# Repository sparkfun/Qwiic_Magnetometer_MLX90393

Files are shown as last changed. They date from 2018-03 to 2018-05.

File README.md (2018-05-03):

SparkFun Qwiic Magnetometer MLX90393
========================================

Qwiic Magnetometer

[*SparkFun Qwiic Magnetometer MLX90393 (14571)*](https://www.sparkfun.com/products/14571)

The SparkFun MLX90393 Magnetometer Breakout is a triple-axis magnetic sensor board capable of sensing very small fields (like the Earth’s magnetic field), while still behaving as one would expect during saturation in larger fields (like a nearby magnet). The MLX90393 breakout can be used as a compass sensor but also works well as a non-contact controller, a flow meter with a magnetic impeller, or a linear actuator position sensor. To make it even easier to to get your readings, all communication is enacted exclusively via I2C, utilizing our handy Qwiic system. However, we still have broken out 0.1"-spaced pins in case you prefer to use a breadboard.

Repository Contents
-------------------

* **/Hardware** - Eagle design files (.brd, .sch)
* **/Production** - Production panel files (.brd)
* **/Software** - Example Code

Documentation
--------------
* **[Arduino Library](https://github.com/tedyapo/arduino-MLX90393)** - Arduino library MLX90393 magnetometer sensor.
* **[Hookup Guide](https://learn.sparkfun.com/tutorials/qwiic-magnetometer-mlx90393-hookup-guide)** - Basic hookup guide for the SparkFun Qwiic Magnetometer MLX90393.
* **[SparkFun Fritzing repo](https://github.com/sparkfun/Fritzing_Parts)** - Fritzing diagrams for SparkFun products. 

License Information
-------------------

This product is _**open source**_! 

Please review the LICENSE.md file for license information. 

If you have any questions or concerns on licensing, please contact techsupport@sparkfun.com.

Distributed as-is; no warranty is given.

- Your friends at SparkFun.

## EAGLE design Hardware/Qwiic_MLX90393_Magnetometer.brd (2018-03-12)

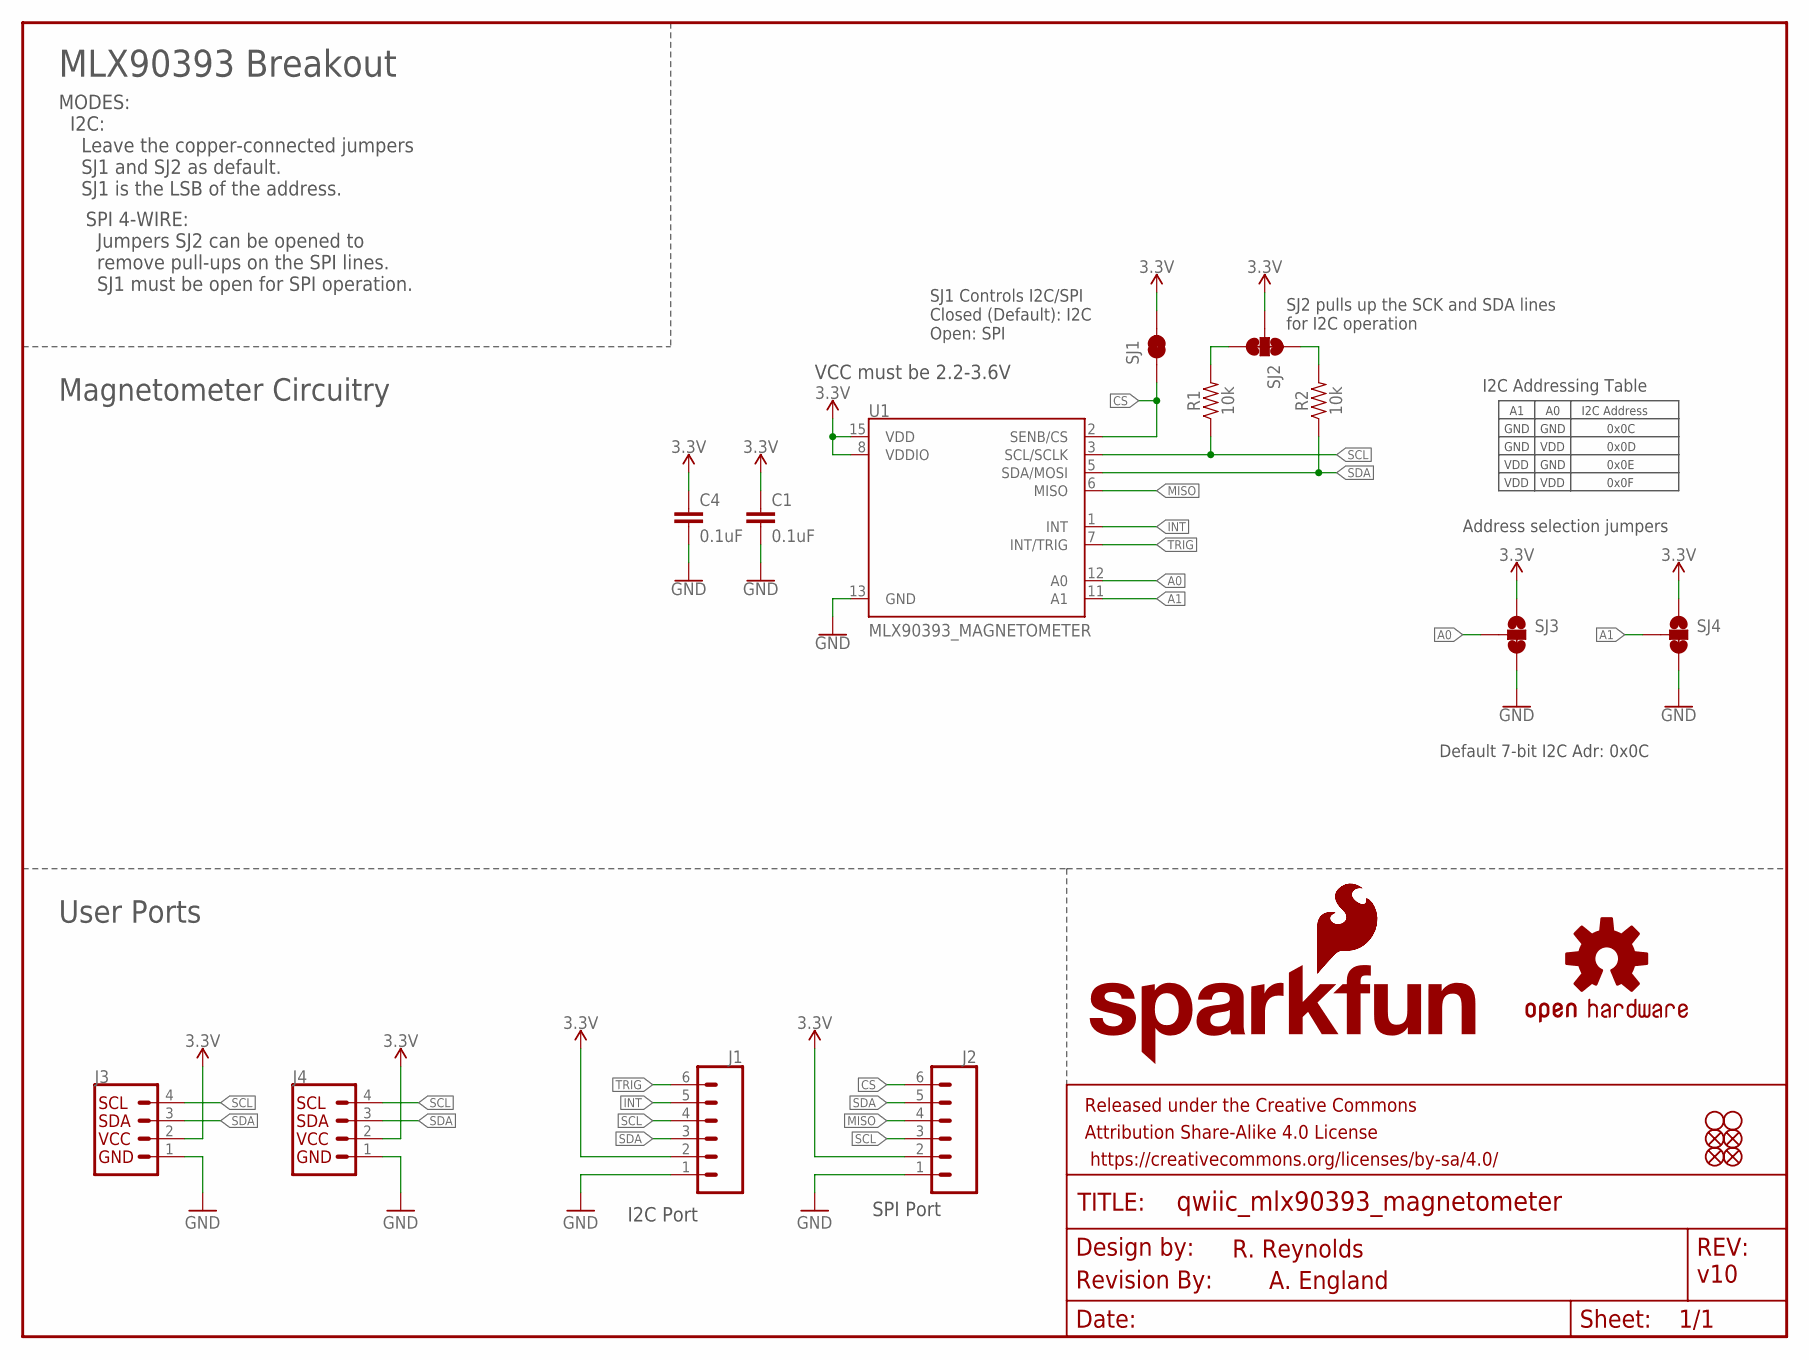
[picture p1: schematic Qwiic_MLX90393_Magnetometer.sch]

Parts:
C1, C4: 0.1uF; 0603
FD1, FD2, FD3, FD4: FIDUCIALUFIDUCIAL; FIDUCIAL-MICRO
FRAME2: FRAME-LETTER; CREATIVE_COMMONS
J1, J2: CONN_06NO_SILK_FEMALE_PTH; 1X06_NO_SILK
J3, J4: QWIIC_CONNECTORJS-1MM; 1X04_1MM_RA
JP3, JP4: STAND-OFF
LOGO1: SFE_LOGO_NAME_FLAME.1_INCH; SFE_LOGO_NAME_FLAME_.1
LOGO2: SFE_LOGO_FLAME.1_INCH; SFE_LOGO_FLAME_.1
LOGO3: REVISION
R1, R2: 10k; 0603
SJ1: JUMPER-SMT_2_NC_TRACE_SILK; SMT-JUMPER_2_NC_TRACE_SILK
SJ2: JUMPER-PAD-3-NC_BY_TRACE; PAD-JUMPER-3-3OF3_NC_BY_TRACE_YES_SILK_FULL_BOX
SJ3, SJ4: JUMPER-SMT_3_1-NC_TRACE_SILK; SMT-JUMPER_3_1-NC_TRACE_SILK
U1: MLX90393_MAGNETOMETER; QFN-16_WITH_AXIES
U$1: OSHW-LOGOS; OSHW-LOGO-S

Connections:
3.3V: C1.1, C4.1, J1.2, J2.2, J3.2, J4.2, SJ1.2, SJ2.2, SJ3.1, SJ4.1, U1.8 (VDDIO), U1.15 (VDD)
A0: SJ3.2, U1.12 (A0)
A1: SJ4.2, U1.11 (A1)
CS: J2.6, SJ1.1, U1.2 (SENB/CS)
GND: C1.2, C4.2, J1.1, J2.1, J3.1, J4.1, SJ3.3, SJ4.3, U1.13 (GND)
INT: J1.5, U1.1 (INT)
MISO: J2.4, U1.6 (MISO)
unnamed: R2.2, SJ2.1
unnamed: R1.2, SJ2.3
SCL: J1.4, J2.3, J3.4, J4.4, R1.1, U1.3 (SCL/SCLK)
SDA: J1.3, J2.5, J3.3, J4.3, R2.1, U1.5 (SDA/MOSI)
TRIG: J1.6, U1.7 (INT/TRIG)

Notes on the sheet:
Address selection jumpers
v10
R. Reynolds
MLX90393 Breakout
SJ2 pulls up the SCK and SDA lines for I2C operation
MODES: I2C: Leave the copper-connected jumpers SJ1 and SJ2 as default. SJ1 is the LSB of the address.
Magnetometer Circuitry
User Ports
VCC must be 2.2-3.6V
SJ1 Controls I2C/SPI Closed (Default): I2C Open: SPI
I2C Port
SPI Port
I2C Address
0x0C
0x0D
0x0E
0x0F
GND
VDD
SPI 4-WIRE: Jumpers SJ2 can be opened to remove pull-ups on the SPI lines. SJ1 must be open for SPI operation.
I2C Addressing Table
Default 7-bit I2C Adr: 0x0C
A. England

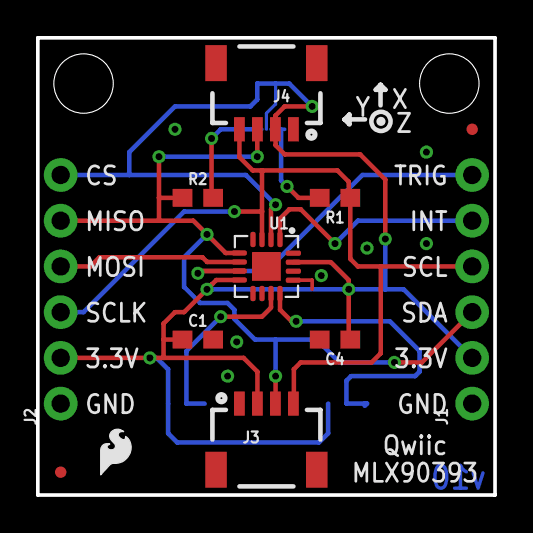
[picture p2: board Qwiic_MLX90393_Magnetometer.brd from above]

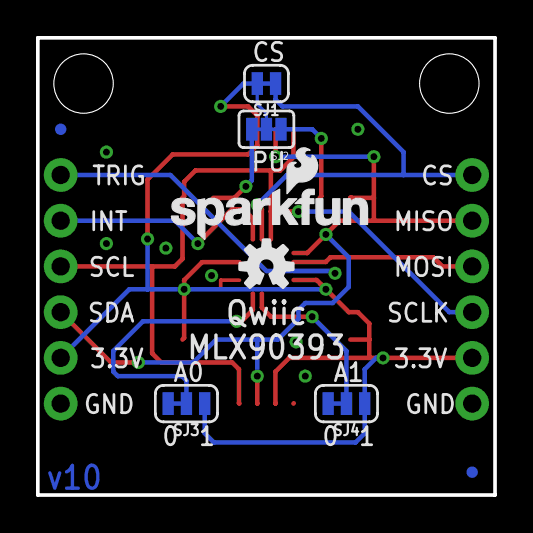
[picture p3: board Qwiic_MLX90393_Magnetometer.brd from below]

Board: 2 copper layers, 25.4 x 25.4 mm, 24 parts (8 on the bottom side), 12 nets.

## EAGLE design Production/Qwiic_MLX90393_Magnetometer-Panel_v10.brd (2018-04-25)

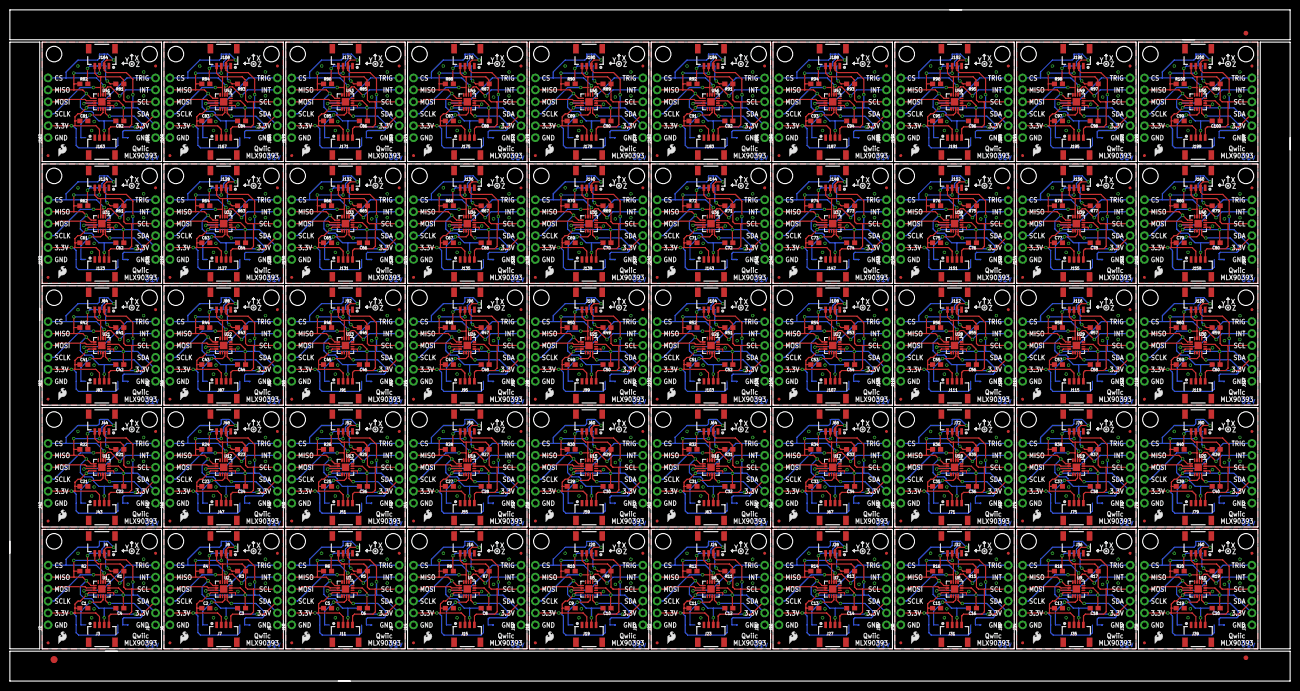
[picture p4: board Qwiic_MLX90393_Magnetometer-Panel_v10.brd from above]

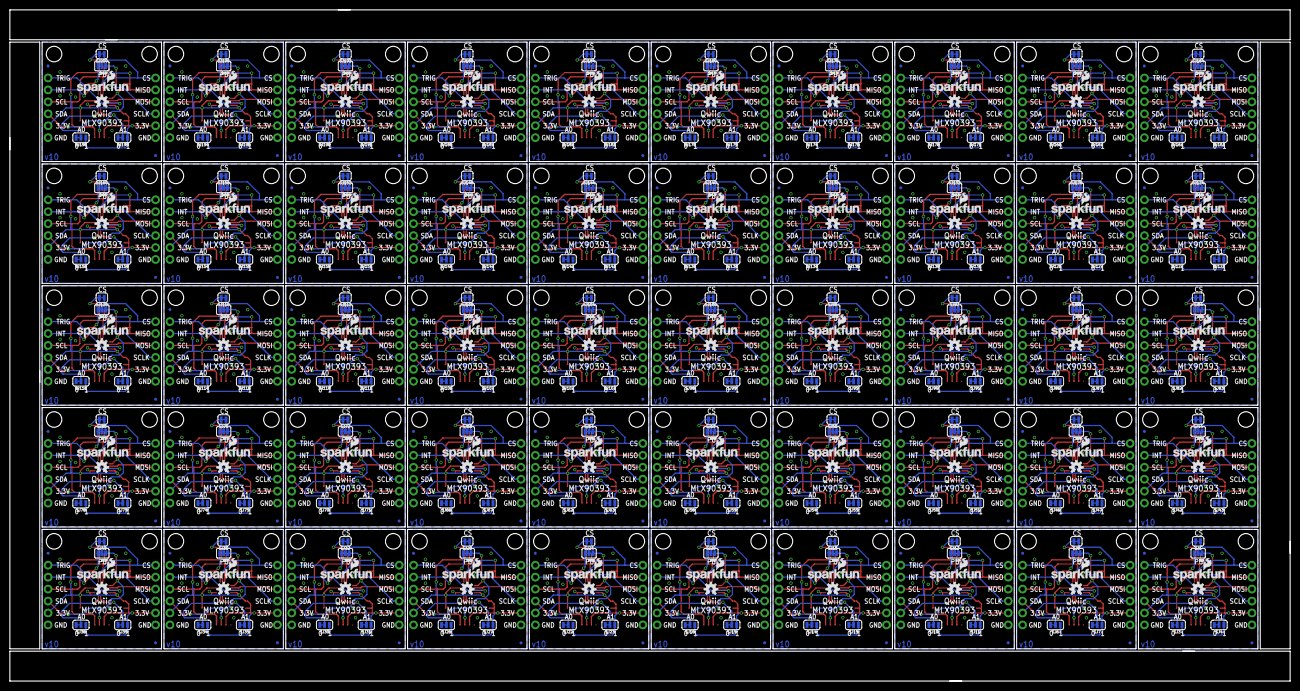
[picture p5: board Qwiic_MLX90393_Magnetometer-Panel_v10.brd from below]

Board: 2 copper layers, 272.3 x 142.7 mm, 1103 parts (400 on the bottom side), 600 nets.

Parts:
C1, C2, C3, C4, C5, C6, C7, C8, C9, C10, C11, C12, C13, C14, C15, C16, C17, C18, C19, C20, C21, C22, C23, C24, C25, C26, C27, C28, C29, C30, C31, C32, C33, C34, C35, C36, C37, C38, C39, C40, C41, C42, C43, C44, C45, C46, C47, C48, C49, C50, C51, C52, C53, C54, C55, C56, C57, C58, C59, C60, C61, C62, C63, C64, C65, C66, C67, C68, C69, C70, C71, C72, C73, C74, C75, C76, C77, C78, C79, C80, C81, C82, C83, C84, C85, C86, C87, C88, C89, C90, C91, C92, C93, C94, C95, C96, C97, C98, C99, C100: 0.1uF; 0603
E$1: FIDUCIAL-1.5X3
E$6, E$7: FIDUCIAL-1X2
FD1, FD2, FD3, FD4, FD5, FD6, FD7, FD8, FD9, FD10, FD11, FD12, FD13, FD14, FD15, FD16, FD17, FD18, FD19, FD20, FD21, FD22, FD23, FD24, FD25, FD26, FD27, FD28, FD29, FD30, FD31, FD32, FD33, FD34, FD35, FD36, FD37, FD38, FD39, FD40, FD41, FD42, FD43, FD44, FD45, FD46, FD47, FD48, FD49, FD50, FD51, FD52, FD53, FD54, FD55, FD56, FD57, FD58, FD59, FD60, FD61, FD62, FD63, FD64, FD65, FD66, FD67, FD68, FD69, FD70, FD71, FD72, FD73, FD74, FD75, FD76, FD77, FD78, FD79, FD80, FD81, FD82, FD83, FD84, FD85, FD86, FD87, FD88, FD89, FD90, FD91, FD92, FD93, FD94, FD95, FD96, FD97, FD98, FD99, FD100, FD101, FD102, FD103, FD104, FD105, FD106, FD107, FD108, FD109, FD110, FD111, FD112, FD113, FD114, FD115, FD116, FD117, FD118, FD119, FD120, FD121, FD122, FD123, FD124, FD125, FD126, FD127, FD128, FD129, FD130, FD131, FD132, FD133, FD134, FD135, FD136, FD137, FD138, FD139, FD140, FD141, FD142, FD143, FD144, FD145, FD146, FD147, FD148, FD149, FD150, FD151, FD152, FD153, FD154, FD155, FD156, FD157, FD158, FD159, FD160, FD161, FD162, FD163, FD164, FD165, FD166, FD167, FD168, FD169, FD170, FD171, FD172, FD173, FD174, FD175, FD176, FD177, FD178, FD179, FD180, FD181, FD182, FD183, FD184, FD185, FD186, FD187, FD188, FD189, FD190, FD191, FD192, FD193, FD194, FD195, FD196, FD197, FD198, FD199, FD200: FIDUCIALUFIDUCIAL; FIDUCIAL-MICRO
J1, J2, J5, J6, J9, J10, J13, J14, J17, J18, J21, J22, J25, J26, J29, J30, J33, J34, J37, J38, J41, J42, J45, J46, J49, J50, J53, J54, J57, J58, J61, J62, J65, J66, J69, J70, J73, J74, J77, J78, J81, J82, J85, J86, J89, J90, J93, J94, J97, J98, J101, J102, J105, J106, J109, J110, J113, J114, J117, J118, J121, J122, J125, J126, J129, J130, J133, J134, J137, J138, J141, J142, J145, J146, J149, J150, J153, J154, J157, J158, J161, J162, J165, J166, J169, J170, J173, J174, J177, J178, J181, J182, J185, J186, J189, J190, J193, J194, J197, J198: 1X06_NO_SILK
J3, J4, J7, J8, J11, J12, J15, J16, J19, J20, J23, J24, J27, J28, J31, J32, J35, J36, J39, J40, J43, J44, J47, J48, J51, J52, J55, J56, J59, J60, J63, J64, J67, J68, J71, J72, J75, J76, J79, J80, J83, J84, J87, J88, J91, J92, J95, J96, J99, J100, J103, J104, J107, J108, J111, J112, J115, J116, J119, J120, J123, J124, J127, J128, J131, J132, J135, J136, J139, J140, J143, J144, J147, J148, J151, J152, J155, J156, J159, J160, J163, J164, J167, J168, J171, J172, J175, J176, J179, J180, J183, J184, J187, J188, J191, J192, J195, J196, J199, J200: 1X04_1MM_RA
JP1, JP2, JP3, JP4, JP5, JP6, JP7, JP8, JP9, JP10, JP11, JP12, JP13, JP14, JP15, JP16, JP17, JP18, JP19, JP20, JP21, JP22, JP23, JP24, JP25, JP26, JP27, JP28, JP29, JP30, JP31, JP32, JP33, JP34, JP35, JP36, JP37, JP38, JP39, JP40, JP41, JP42, JP43, JP44, JP45, JP46, JP47, JP48, JP49, JP50, JP51, JP52, JP53, JP54, JP55, JP56, JP57, JP58, JP59, JP60, JP61, JP62, JP63, JP64, JP65, JP66, JP67, JP68, JP69, JP70, JP71, JP72, JP73, JP74, JP75, JP76, JP77, JP78, JP79, JP80, JP81, JP82, JP83, JP84, JP85, JP86, JP87, JP88, JP89, JP90, JP91, JP92, JP93, JP94, JP95, JP96, JP97, JP98, JP99, JP100: STAND-OFF
LOGO1, LOGO3, LOGO5, LOGO7, LOGO9, LOGO11, LOGO13, LOGO15, LOGO17, LOGO19, LOGO21, LOGO23, LOGO25, LOGO27, LOGO29, LOGO31, LOGO33, LOGO35, LOGO37, LOGO39, LOGO41, LOGO43, LOGO45, LOGO47, LOGO49, LOGO51, LOGO53, LOGO55, LOGO57, LOGO59, LOGO61, LOGO63, LOGO65, LOGO67, LOGO69, LOGO71, LOGO73, LOGO75, LOGO77, LOGO79, LOGO81, LOGO83, LOGO85, LOGO87, LOGO89, LOGO91, LOGO93, LOGO95, LOGO97, LOGO99: SFE_LOGO_NAME_FLAME.1_INCH; SFE_LOGO_NAME_FLAME_.1
LOGO2, LOGO4, LOGO6, LOGO8, LOGO10, LOGO12, LOGO14, LOGO16, LOGO18, LOGO20, LOGO22, LOGO24, LOGO26, LOGO28, LOGO30, LOGO32, LOGO34, LOGO36, LOGO38, LOGO40, LOGO42, LOGO44, LOGO46, LOGO48, LOGO50, LOGO52, LOGO54, LOGO56, LOGO58, LOGO60, LOGO62, LOGO64, LOGO66, LOGO68, LOGO70, LOGO72, LOGO74, LOGO76, LOGO78, LOGO80, LOGO82, LOGO84, LOGO86, LOGO88, LOGO90, LOGO92, LOGO94, LOGO96, LOGO98, LOGO100: SFE_LOGO_FLAME.1_INCH; SFE_LOGO_FLAME_.1
R1, R2, R3, R4, R5, R6, R7, R8, R9, R10, R11, R12, R13, R14, R15, R16, R17, R18, R19, R20, R21, R22, R23, R24, R25, R26, R27, R28, R29, R30, R31, R32, R33, R34, R35, R36, R37, R38, R39, R40, R41, R42, R43, R44, R45, R46, R47, R48, R49, R50, R51, R52, R53, R54, R55, R56, R57, R58, R59, R60, R61, R62, R63, R64, R65, R66, R67, R68, R69, R70, R71, R72, R73, R74, R75, R76, R77, R78, R79, R80, R81, R82, R83, R84, R85, R86, R87, R88, R89, R90, R91, R92, R93, R94, R95, R96, R97, R98, R99, R100: 10k; 0603
SJ1, SJ8, SJ12, SJ16, SJ20, SJ24, SJ28, SJ32, SJ36, SJ40, SJ44, SJ48, SJ52, SJ56, SJ60, SJ64, SJ68, SJ72, SJ76, SJ80, SJ84, SJ88, SJ92, SJ96, SJ100, SJ104, SJ108, SJ112, SJ116, SJ120, SJ124, SJ128, SJ132, SJ136, SJ140, SJ144, SJ148, SJ152, SJ156, SJ160, SJ164, SJ168, SJ172, SJ176, SJ180, SJ184, SJ188, SJ192, SJ196, SJ200: SMT-JUMPER_2_NC_TRACE_SILK
SJ2, SJ5, SJ9, SJ13, SJ17, SJ21, SJ25, SJ29, SJ33, SJ37, SJ41, SJ45, SJ49, SJ53, SJ57, SJ61, SJ65, SJ69, SJ73, SJ77, SJ81, SJ85, SJ89, SJ93, SJ97, SJ101, SJ105, SJ109, SJ113, SJ117, SJ121, SJ125, SJ129, SJ133, SJ137, SJ141, SJ145, SJ149, SJ153, SJ157, SJ161, SJ165, SJ169, SJ173, SJ177, SJ181, SJ185, SJ189, SJ193, SJ197: PAD-JUMPER-3-3OF3_NC_BY_TRACE_YES_SILK_FULL_BOX
SJ3, SJ4, SJ6, SJ7, SJ10, SJ11, SJ14, SJ15, SJ18, SJ19, SJ22, SJ23, SJ26, SJ27, SJ30, SJ31, SJ34, SJ35, SJ38, SJ39, SJ42, SJ43, SJ46, SJ47, SJ50, SJ51, SJ54, SJ55, SJ58, SJ59, SJ62, SJ63, SJ66, SJ67, SJ70, SJ71, SJ74, SJ75, SJ78, SJ79, SJ82, SJ83, SJ86, SJ87, SJ90, SJ91, SJ94, SJ95, SJ98, SJ99, SJ102, SJ103, SJ106, SJ107, SJ110, SJ111, SJ114, SJ115, SJ118, SJ119, SJ122, SJ123, SJ126, SJ127, SJ130, SJ131, SJ134, SJ135, SJ138, SJ139, SJ142, SJ143, SJ146, SJ147, SJ150, SJ151, SJ154, SJ155, SJ158, SJ159, SJ162, SJ163, SJ166, SJ167, SJ170, SJ171, SJ174, SJ175, SJ178, SJ179, SJ182, SJ183, SJ186, SJ187, SJ190, SJ191, SJ194, SJ195, SJ198, SJ199: SMT-JUMPER_3_1-NC_TRACE_SILK
U1, U2, U3, U4, U5, U6, U7, U8, U9, U10, U11, U12, U13, U14, U15, U16, U17, U18, U19, U20, U21, U22, U23, U24, U25, U26, U27, U28, U29, U30, U31, U32, U33, U34, U35, U36, U37, U38, U39, U40, U41, U42, U43, U44, U45, U46, U47, U48, U49, U50: MLX90393_MAGNETOMETER; QFN-16_WITH_AXIES
U$1, U$2, U$3, U$4, U$5, U$6, U$7, U$8, U$9, U$10, U$11, U$12, U$13, U$14, U$15, U$16, U$17, U$18, U$19, U$20, U$21, U$22, U$23, U$24, U$25, U$26, U$27, U$28, U$29, U$30, U$31, U$32, U$33, U$34, U$35, U$36, U$37, U$38, U$39, U$40, U$41, U$42, U$43, U$44, U$45, U$46, U$47, U$48, U$49, U$50: OSHW-LOGOS; OSHW-LOGO-S

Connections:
3.3V: C1.1, C4.1, J1.2, J2.2, J3.2, J4.2, SJ1.2, SJ2.2, SJ3.1, SJ4.1, U1.8, U1.15
3.3V1: C2.1, C3.1, J5.2, J6.2, J7.2, J8.2, SJ5.2, SJ6.1, SJ7.1, SJ8.2, U2.8, U2.15
3.3V2: C5.1, C6.1, J9.2, J10.2, J11.2, J12.2, SJ9.2, SJ10.1, SJ11.1, SJ12.2, U3.8, U3.15
3.3V3: C7.1, C8.1, J13.2, J14.2, J15.2, J16.2, SJ13.2, SJ14.1, SJ15.1, SJ16.2, U4.8, U4.15
3.3V4: C9.1, C10.1, J17.2, J18.2, J19.2, J20.2, SJ17.2, SJ18.1, SJ19.1, SJ20.2, U5.8, U5.15
3.3V5: C11.1, C12.1, J21.2, J22.2, J23.2, J24.2, SJ21.2, SJ22.1, SJ23.1, SJ24.2, U6.8, U6.15
3.3V6: C13.1, C14.1, J25.2, J26.2, J27.2, J28.2, SJ25.2, SJ26.1, SJ27.1, SJ28.2, U7.8, U7.15
3.3V7: C15.1, C16.1, J29.2, J30.2, J31.2, J32.2, SJ29.2, SJ30.1, SJ31.1, SJ32.2, U8.8, U8.15
3.3V8: C17.1, C18.1, J33.2, J34.2, J35.2, J36.2, SJ33.2, SJ34.1, SJ35.1, SJ36.2, U9.8, U9.15
3.3V9: C19.1, C20.1, J37.2, J38.2, J39.2, J40.2, SJ37.2, SJ38.1, SJ39.1, SJ40.2, U10.8, U10.15
3.3V10: C21.1, C22.1, J41.2, J42.2, J43.2, J44.2, SJ41.2, SJ42.1, SJ43.1, SJ44.2, U11.8, U11.15
3.3V11: C23.1, C24.1, J45.2, J46.2, J47.2, J48.2, SJ45.2, SJ46.1, SJ47.1, SJ48.2, U12.8, U12.15
3.3V12: C25.1, C26.1, J49.2, J50.2, J51.2, J52.2, SJ49.2, SJ50.1, SJ51.1, SJ52.2, U13.8, U13.15
3.3V13: C27.1, C28.1, J53.2, J54.2, J55.2, J56.2, SJ53.2, SJ54.1, SJ55.1, SJ56.2, U14.8, U14.15
3.3V14: C29.1, C30.1, J57.2, J58.2, J59.2, J60.2, SJ57.2, SJ58.1, SJ59.1, SJ60.2, U15.8, U15.15
3.3V15: C31.1, C32.1, J61.2, J62.2, J63.2, J64.2, SJ61.2, SJ62.1, SJ63.1, SJ64.2, U16.8, U16.15
3.3V16: C33.1, C34.1, J65.2, J66.2, J67.2, J68.2, SJ65.2, SJ66.1, SJ67.1, SJ68.2, U17.8, U17.15
3.3V17: C35.1, C36.1, J69.2, J70.2, J71.2, J72.2, SJ69.2, SJ70.1, SJ71.1, SJ72.2, U18.8, U18.15
3.3V18: C37.1, C38.1, J73.2, J74.2, J75.2, J76.2, SJ73.2, SJ74.1, SJ75.1, SJ76.2, U19.8, U19.15
3.3V19: C39.1, C40.1, J77.2, J78.2, J79.2, J80.2, SJ77.2, SJ78.1, SJ79.1, SJ80.2, U20.8, U20.15
3.3V20: C41.1, C42.1, J81.2, J82.2, J83.2, J84.2, SJ81.2, SJ82.1, SJ83.1, SJ84.2, U21.8, U21.15
3.3V21: C43.1, C44.1, J85.2, J86.2, J87.2, J88.2, SJ85.2, SJ86.1, SJ87.1, SJ88.2, U22.8, U22.15
3.3V22: C45.1, C46.1, J89.2, J90.2, J91.2, J92.2, SJ89.2, SJ90.1, SJ91.1, SJ92.2, U23.8, U23.15
3.3V23: C47.1, C48.1, J93.2, J94.2, J95.2, J96.2, SJ93.2, SJ94.1, SJ95.1, SJ96.2, U24.8, U24.15
3.3V24: C49.1, C50.1, J97.2, J98.2, J99.2, J100.2, SJ97.2, SJ98.1, SJ99.1, SJ100.2, U25.8, U25.15
3.3V25: C51.1, C52.1, J101.2, J102.2, J103.2, J104.2, SJ101.2, SJ102.1, SJ103.1, SJ104.2, U26.8, U26.15
3.3V26: C53.1, C54.1, J105.2, J106.2, J107.2, J108.2, SJ105.2, SJ106.1, SJ107.1, SJ108.2, U27.8, U27.15
3.3V27: C55.1, C56.1, J109.2, J110.2, J111.2, J112.2, SJ109.2, SJ110.1, SJ111.1, SJ112.2, U28.8, U28.15
3.3V28: C57.1, C58.1, J113.2, J114.2, J115.2, J116.2, SJ113.2, SJ114.1, SJ115.1, SJ116.2, U29.8, U29.15
3.3V29: C59.1, C60.1, J117.2, J118.2, J119.2, J120.2, SJ117.2, SJ118.1, SJ119.1, SJ120.2, U30.8, U30.15
3.3V30: C61.1, C62.1, J121.2, J122.2, J123.2, J124.2, SJ121.2, SJ122.1, SJ123.1, SJ124.2, U31.8, U31.15
3.3V31: C63.1, C64.1, J125.2, J126.2, J127.2, J128.2, SJ125.2, SJ126.1, SJ127.1, SJ128.2, U32.8, U32.15
3.3V32: C65.1, C66.1, J129.2, J130.2, J131.2, J132.2, SJ129.2, SJ130.1, SJ131.1, SJ132.2, U33.8, U33.15
3.3V33: C67.1, C68.1, J133.2, J134.2, J135.2, J136.2, SJ133.2, SJ134.1, SJ135.1, SJ136.2, U34.8, U34.15
3.3V34: C69.1, C70.1, J137.2, J138.2, J139.2, J140.2, SJ137.2, SJ138.1, SJ139.1, SJ140.2, U35.8, U35.15
3.3V35: C71.1, C72.1, J141.2, J142.2, J143.2, J144.2, SJ141.2, SJ142.1, SJ143.1, SJ144.2, U36.8, U36.15
3.3V36: C73.1, C74.1, J145.2, J146.2, J147.2, J148.2, SJ145.2, SJ146.1, SJ147.1, SJ148.2, U37.8, U37.15
3.3V37: C75.1, C76.1, J149.2, J150.2, J151.2, J152.2, SJ149.2, SJ150.1, SJ151.1, SJ152.2, U38.8, U38.15
3.3V38: C77.1, C78.1, J153.2, J154.2, J155.2, J156.2, SJ153.2, SJ154.1, SJ155.1, SJ156.2, U39.8, U39.15
3.3V39: C79.1, C80.1, J157.2, J158.2, J159.2, J160.2, SJ157.2, SJ158.1, SJ159.1, SJ160.2, U40.8, U40.15
3.3V40: C81.1, C82.1, J161.2, J162.2, J163.2, J164.2, SJ161.2, SJ162.1, SJ163.1, SJ164.2, U41.8, U41.15
3.3V41: C83.1, C84.1, J165.2, J166.2, J167.2, J168.2, SJ165.2, SJ166.1, SJ167.1, SJ168.2, U42.8, U42.15
3.3V42: C85.1, C86.1, J169.2, J170.2, J171.2, J172.2, SJ169.2, SJ170.1, SJ171.1, SJ172.2, U43.8, U43.15
3.3V43: C87.1, C88.1, J173.2, J174.2, J175.2, J176.2, SJ173.2, SJ174.1, SJ175.1, SJ176.2, U44.8, U44.15
3.3V44: C89.1, C90.1, J177.2, J178.2, J179.2, J180.2, SJ177.2, SJ178.1, SJ179.1, SJ180.2, U45.8, U45.15
3.3V45: C91.1, C92.1, J181.2, J182.2, J183.2, J184.2, SJ181.2, SJ182.1, SJ183.1, SJ184.2, U46.8, U46.15
3.3V46: C93.1, C94.1, J185.2, J186.2, J187.2, J188.2, SJ185.2, SJ186.1, SJ187.1, SJ188.2, U47.8, U47.15
3.3V47: C95.1, C96.1, J189.2, J190.2, J191.2, J192.2, SJ189.2, SJ190.1, SJ191.1, SJ192.2, U48.8, U48.15
3.3V48: C97.1, C98.1, J193.2, J194.2, J195.2, J196.2, SJ193.2, SJ194.1, SJ195.1, SJ196.2, U49.8, U49.15
3.3V49: C99.1, C100.1, J197.2, J198.2, J199.2, J200.2, SJ197.2, SJ198.1, SJ199.1, SJ200.2, U50.8, U50.15
A0: SJ3.2, U1.12
A1: SJ4.2, U1.11
A2: SJ6.2, U2.12
A3: SJ7.2, U2.11
A4: SJ10.2, U3.12
A5: SJ11.2, U3.11
A6: SJ14.2, U4.12
A7: SJ15.2, U4.11
A8: SJ18.2, U5.12
A9: SJ19.2, U5.11
A10: SJ22.2, U6.12
A11: SJ23.2, U6.11
A12: SJ26.2, U7.12
A13: SJ27.2, U7.11
A14: SJ30.2, U8.12
A15: SJ31.2, U8.11
A16: SJ34.2, U9.12
A17: SJ35.2, U9.11
A18: SJ38.2, U10.12
A19: SJ39.2, U10.11
A20: SJ42.2, U11.12
A21: SJ43.2, U11.11
A22: SJ46.2, U12.12
A23: SJ47.2, U12.11
A24: SJ50.2, U13.12
A25: SJ51.2, U13.11
A26: SJ54.2, U14.12
A27: SJ55.2, U14.11
A28: SJ58.2, U15.12
A29: SJ59.2, U15.11
A30: SJ62.2, U16.12
A31: SJ63.2, U16.11
A32: SJ66.2, U17.12
A33: SJ67.2, U17.11
A34: SJ70.2, U18.12
A35: SJ71.2, U18.11
A36: SJ74.2, U19.12
A37: SJ75.2, U19.11
A38: SJ78.2, U20.12
A39: SJ79.2, U20.11
A40: SJ82.2, U21.12
A41: SJ83.2, U21.11
A42: SJ86.2, U22.12
A43: SJ87.2, U22.11
A44: SJ90.2, U23.12
A45: SJ91.2, U23.11
A46: SJ94.2, U24.12
A47: SJ95.2, U24.11
A48: SJ98.2, U25.12
A49: SJ99.2, U25.11
A50: SJ102.2, U26.12
A51: SJ103.2, U26.11
A52: SJ106.2, U27.12
A53: SJ107.2, U27.11
A54: SJ110.2, U28.12
A55: SJ111.2, U28.11
A56: SJ114.2, U29.12
A57: SJ115.2, U29.11
A58: SJ118.2, U30.12
A59: SJ119.2, U30.11
A60: SJ122.2, U31.12
A61: SJ123.2, U31.11
A62: SJ126.2, U32.12
A63: SJ127.2, U32.11
A64: SJ130.2, U33.12
A65: SJ131.2, U33.11
A66: SJ134.2, U34.12
A67: SJ135.2, U34.11
A68: SJ138.2, U35.12
A69: SJ139.2, U35.11
A70: SJ142.2, U36.12
A71: SJ143.2, U36.11
A72: SJ146.2, U37.12
A73: SJ147.2, U37.11
A74: SJ150.2, U38.12
A75: SJ151.2, U38.11
A76: SJ154.2, U39.12
A77: SJ155.2, U39.11
A78: SJ158.2, U40.12
A79: SJ159.2, U40.11
A80: SJ162.2, U41.12
A81: SJ163.2, U41.11
A82: SJ166.2, U42.12
A83: SJ167.2, U42.11
A84: SJ170.2, U43.12
A85: SJ171.2, U43.11
A86: SJ174.2, U44.12
A87: SJ175.2, U44.11
A88: SJ178.2, U45.12
A89: SJ179.2, U45.11
A90: SJ182.2, U46.12
A91: SJ183.2, U46.11
A92: SJ186.2, U47.12
A93: SJ187.2, U47.11
A94: SJ190.2, U48.12
A95: SJ191.2, U48.11
A96: SJ194.2, U49.12
A97: SJ195.2, U49.11
A98: SJ198.2, U50.12
A99: SJ199.2, U50.11
CS: J2.6, SJ1.1, U1.2
CS1: J6.6, SJ8.1, U2.2
CS2: J10.6, SJ12.1, U3.2
CS3: J14.6, SJ16.1, U4.2
CS4: J18.6, SJ20.1, U5.2
CS5: J22.6, SJ24.1, U6.2
CS6: J26.6, SJ28.1, U7.2
CS7: J30.6, SJ32.1, U8.2
CS8: J34.6, SJ36.1, U9.2
CS9: J38.6, SJ40.1, U10.2
CS10: J42.6, SJ44.1, U11.2
CS11: J46.6, SJ48.1, U12.2
CS12: J50.6, SJ52.1, U13.2
CS13: J54.6, SJ56.1, U14.2
CS14: J58.6, SJ60.1, U15.2
CS15: J62.6, SJ64.1, U16.2
CS16: J66.6, SJ68.1, U17.2
CS17: J70.6, SJ72.1, U18.2
CS18: J74.6, SJ76.1, U19.2
CS19: J78.6, SJ80.1, U20.2
CS20: J82.6, SJ84.1, U21.2
CS21: J86.6, SJ88.1, U22.2
CS22: J90.6, SJ92.1, U23.2
CS23: J94.6, SJ96.1, U24.2
CS24: J98.6, SJ100.1, U25.2
CS25: J102.6, SJ104.1, U26.2
CS26: J106.6, SJ108.1, U27.2
CS27: J110.6, SJ112.1, U28.2
CS28: J114.6, SJ116.1, U29.2
CS29: J118.6, SJ120.1, U30.2
CS30: J122.6, SJ124.1, U31.2
CS31: J126.6, SJ128.1, U32.2
CS32: J130.6, SJ132.1, U33.2
CS33: J134.6, SJ136.1, U34.2
CS34: J138.6, SJ140.1, U35.2
CS35: J142.6, SJ144.1, U36.2
CS36: J146.6, SJ148.1, U37.2
CS37: J150.6, SJ152.1, U38.2
CS38: J154.6, SJ156.1, U39.2
CS39: J158.6, SJ160.1, U40.2
CS40: J162.6, SJ164.1, U41.2
CS41: J166.6, SJ168.1, U42.2
CS42: J170.6, SJ172.1, U43.2
CS43: J174.6, SJ176.1, U44.2
CS44: J178.6, SJ180.1, U45.2
CS45: J182.6, SJ184.1, U46.2
CS46: J186.6, SJ188.1, U47.2
CS47: J190.6, SJ192.1, U48.2
CS48: J194.6, SJ196.1, U49.2
CS49: J198.6, SJ200.1, U50.2
GND: C1.2, C4.2, J1.1, J2.1, J3.1, J4.1, SJ3.3, SJ4.3, U1.13
GND1: C2.2, C3.2, J5.1, J6.1, J7.1, J8.1, SJ6.3, SJ7.3, U2.13
GND2: C5.2, C6.2, J9.1, J10.1, J11.1, J12.1, SJ10.3, SJ11.3, U3.13
GND3: C7.2, C8.2, J13.1, J14.1, J15.1, J16.1, SJ14.3, SJ15.3, U4.13
GND4: C9.2, C10.2, J17.1, J18.1, J19.1, J20.1, SJ18.3, SJ19.3, U5.13
GND5: C11.2, C12.2, J21.1, J22.1, J23.1, J24.1, SJ22.3, SJ23.3, U6.13
GND6: C13.2, C14.2, J25.1, J26.1, J27.1, J28.1, SJ26.3, SJ27.3, U7.13
GND7: C15.2, C16.2, J29.1, J30.1, J31.1, J32.1, SJ30.3, SJ31.3, U8.13
GND8: C17.2, C18.2, J33.1, J34.1, J35.1, J36.1, SJ34.3, SJ35.3, U9.13
GND9: C19.2, C20.2, J37.1, J38.1, J39.1, J40.1, SJ38.3, SJ39.3, U10.13
GND10: C21.2, C22.2, J41.1, J42.1, J43.1, J44.1, SJ42.3, SJ43.3, U11.13
GND11: C23.2, C24.2, J45.1, J46.1, J47.1, J48.1, SJ46.3, SJ47.3, U12.13
GND12: C25.2, C26.2, J49.1, J50.1, J51.1, J52.1, SJ50.3, SJ51.3, U13.13
GND13: C27.2, C28.2, J53.1, J54.1, J55.1, J56.1, SJ54.3, SJ55.3, U14.13
GND14: C29.2, C30.2, J57.1, J58.1, J59.1, J60.1, SJ58.3, SJ59.3, U15.13
GND15: C31.2, C32.2, J61.1, J62.1, J63.1, J64.1, SJ62.3, SJ63.3, U16.13
GND16: C33.2, C34.2, J65.1, J66.1, J67.1, J68.1, SJ66.3, SJ67.3, U17.13
GND17: C35.2, C36.2, J69.1, J70.1, J71.1, J72.1, SJ70.3, SJ71.3, U18.13
GND18: C37.2, C38.2, J73.1, J74.1, J75.1, J76.1, SJ74.3, SJ75.3, U19.13
GND19: C39.2, C40.2, J77.1, J78.1, J79.1, J80.1, SJ78.3, SJ79.3, U20.13
GND20: C41.2, C42.2, J81.1, J82.1, J83.1, J84.1, SJ82.3, SJ83.3, U21.13
GND21: C43.2, C44.2, J85.1, J86.1, J87.1, J88.1, SJ86.3, SJ87.3, U22.13
GND22: C45.2, C46.2, J89.1, J90.1, J91.1, J92.1, SJ90.3, SJ91.3, U23.13
GND23: C47.2, C48.2, J93.1, J94.1, J95.1, J96.1, SJ94.3, SJ95.3, U24.13
GND24: C49.2, C50.2, J97.1, J98.1, J99.1, J100.1, SJ98.3, SJ99.3, U25.13
GND25: C51.2, C52.2, J101.1, J102.1, J103.1, J104.1, SJ102.3, SJ103.3, U26.13
GND26: C53.2, C54.2, J105.1, J106.1, J107.1, J108.1, SJ106.3, SJ107.3, U27.13
GND27: C55.2, C56.2, J109.1, J110.1, J111.1, J112.1, SJ110.3, SJ111.3, U28.13
GND28: C57.2, C58.2, J113.1, J114.1, J115.1, J116.1, SJ114.3, SJ115.3, U29.13
GND29: C59.2, C60.2, J117.1, J118.1, J119.1, J120.1, SJ118.3, SJ119.3, U30.13
GND30: C61.2, C62.2, J121.1, J122.1, J123.1, J124.1, SJ122.3, SJ123.3, U31.13
GND31: C63.2, C64.2, J125.1, J126.1, J127.1, J128.1, SJ126.3, SJ127.3, U32.13
GND32: C65.2, C66.2, J129.1, J130.1, J131.1, J132.1, SJ130.3, SJ131.3, U33.13
GND33: C67.2, C68.2, J133.1, J134.1, J135.1, J136.1, SJ134.3, SJ135.3, U34.13
GND34: C69.2, C70.2, J137.1, J138.1, J139.1, J140.1, SJ138.3, SJ139.3, U35.13
GND35: C71.2, C72.2, J141.1, J142.1, J143.1, J144.1, SJ142.3, SJ143.3, U36.13
GND36: C73.2, C74.2, J145.1, J146.1, J147.1, J148.1, SJ146.3, SJ147.3, U37.13
GND37: C75.2, C76.2, J149.1, J150.1, J151.1, J152.1, SJ150.3, SJ151.3, U38.13
GND38: C77.2, C78.2, J153.1, J154.1, J155.1, J156.1, SJ154.3, SJ155.3, U39.13
GND39: C79.2, C80.2, J157.1, J158.1, J159.1, J160.1, SJ158.3, SJ159.3, U40.13
GND40: C81.2, C82.2, J161.1, J162.1, J163.1, J164.1, SJ162.3, SJ163.3, U41.13
GND41: C83.2, C84.2, J165.1, J166.1, J167.1, J168.1, SJ166.3, SJ167.3, U42.13
GND42: C85.2, C86.2, J169.1, J170.1, J171.1, J172.1, SJ170.3, SJ171.3, U43.13
GND43: C87.2, C88.2, J173.1, J174.1, J175.1, J176.1, SJ174.3, SJ175.3, U44.13
GND44: C89.2, C90.2, J177.1, J178.1, J179.1, J180.1, SJ178.3, SJ179.3, U45.13
GND45: C91.2, C92.2, J181.1, J182.1, J183.1, J184.1, SJ182.3, SJ183.3, U46.13
GND46: C93.2, C94.2, J185.1, J186.1, J187.1, J188.1, SJ186.3, SJ187.3, U47.13
GND47: C95.2, C96.2, J189.1, J190.1, J191.1, J192.1, SJ190.3, SJ191.3, U48.13
GND48: C97.2, C98.2, J193.1, J194.1, J195.1, J196.1, SJ194.3, SJ195.3, U49.13
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

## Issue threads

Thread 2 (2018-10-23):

Connecting 6x sensors to Teensy 3.6

akrv, 2018-10-23:
with `A0` and `A1` pins, it is possible to address up to 4 sensors.
how can I connect two more sensors?

I quote from the [datasheet](https://cdn.sparkfun.com/assets/e/e/f/2/7/MLX90393-Datasheet-Melexis.PDF)

> I2C_ADDR[6:0] = {EE_I2C_ADDR[4:0],A1,A0} with Ai the user-selectable active-high value of the input pads of the MLX90393, referred to the VDD supply system and EE_I2C_ADDR[4:0] default programmed to 03h, but user accessible for overwrite.

is there a possibility to change the address?
any help would be appreciated?

nseidle, 2018-11-03:
Hi, Yes it looks like EE_I2C_ADDR[4:0] can be overwritten to accommodate many magnetometers on a single I2C bus.

> I2C_ADDR[6:0] = {EE_I2C_ADDR[4:0],A1,A0} with Ai the user-selectable active-high value of the input pads of the MLX90393, referred to the VDD supply system and EE_I2C_ADDR[4:0] default programmed to 03h, but user accessible for overwrite.

But I can't find the memory location for that register...

[Different datasheet here](http://static6.arrow.com/aropdfconversion/6a2d69f975cb6d54620e77b89738a2edb6eb7eed/2mlx90393-datasheet-melexis.pdf.pdf).

>I2C_ADDR[6:0] = {EE_I2C_ADDR[4:0],A1,A0} with Ai the user-selectable active-high value of the input pads of the MLX90393, referred to the VDD supply system and EE_I2C_ADDR[4:0] default programmed to 0x03h, but factory accessible for overwrite.

So unfortunately it's factory writable, not user writable. SparkFun only offers MLX90393xLW-ABA-011-RE but in theory you could do your own board and solder on different MLX90393s. The easier option is to use the [Qwiic Mux](https://www.sparkfun.com/products/14685).

Hope this helps!

Closed 2018-11-03.

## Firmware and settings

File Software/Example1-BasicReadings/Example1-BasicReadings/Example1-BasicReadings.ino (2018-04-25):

/*
  MLX90393 Magnetometer Example Code
  By: Nathan Seidle
  SparkFun Electronics
  Date: February 6th, 2017
  License: This code is public domain but you buy me a beer if you use this and we meet someday (Beerware license).

  Read the mag fields on three XYZ axis

  Hardware Connections (Breakoutboard to Arduino):
  3.3V = 3.3V
  GND = GND
  SDA = A4
  SCL = A5

  Serial.print it out at 9600 baud to serial monitor.
*/

#include <Wire.h>
#include <MLX90393.h> //From https://github.com/tedyapo/arduino-MLX90393 by Theodore Yapo

MLX90393 mlx;
MLX90393::txyz data; //Create a structure, called data, of four floats (t, x, y, and z)

void setup()
{
  Serial.begin(9600);
  Serial.println("MLX90393 Read Example");
  Wire.begin();
  mlx.begin(); //Assumes I2C jumpers are GND. No DRDY pin used.
  mlx.setOverSampling(0);
  mlx.setDigitalFiltering(0);
}

void loop()
{
  mlx.readData(data); //Read the values from the sensor

  Serial.print("magX[");
  Serial.print(data.x);
  Serial.print("] magY[");
  Serial.print(data.y);
  Serial.print("] magZ[");
  Serial.print(data.z);
  Serial.print("] temperature(C)[");
  Serial.print(data.t);
  Serial.print("]");

  Serial.println();

  delay(1);
}

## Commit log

2018-01-02 converted from SparkX
    [Qwiic_MLX90393_Magnetometer.brd, Qwiic_MLX90393_Magnetometer.sch]
2018-01-24 updated magnetometer
2018-01-24 post qc checklist changes
    [Qwiic_MLX90393_Magnetometer.brd, Qwiic_MLX90393_Magnetometer.sch]
2018-01-25 fixed version number
    [Qwiic_MLX90393_Magnetometer.brd, Qwiic_MLX90393_Magnetometer.sch]
2018-02-16 updated footprint for magnetometer
    [Qwiic_MLX90393_Magnetometer.GBL, Qwiic_MLX90393_Magnetometer.GBO, Qwiic_MLX90393_Magnetometer.GBS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]
2018-03-08 repo reorg
    [Qwiic_MLX90393_Magnetometer.sch]
2018-03-12 post checklist changes
    [Qwiic_MLX90393_Magnetometer.brd, Qwiic_MLX90393_Magnetometer.sch]
2018-03-22 created panel v10
    [Qwiic_MLX90393_Magnetometer-Panel_v10.brd]

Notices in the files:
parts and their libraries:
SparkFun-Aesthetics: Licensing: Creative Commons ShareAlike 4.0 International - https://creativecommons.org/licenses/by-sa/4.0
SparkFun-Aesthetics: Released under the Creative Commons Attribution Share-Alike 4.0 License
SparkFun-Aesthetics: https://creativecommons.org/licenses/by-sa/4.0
